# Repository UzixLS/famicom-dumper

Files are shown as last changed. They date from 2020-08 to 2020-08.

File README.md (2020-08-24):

# Famicom Dumper/Programmer

## Overview

This is simple dumper/programmer for Famicom cartridges.

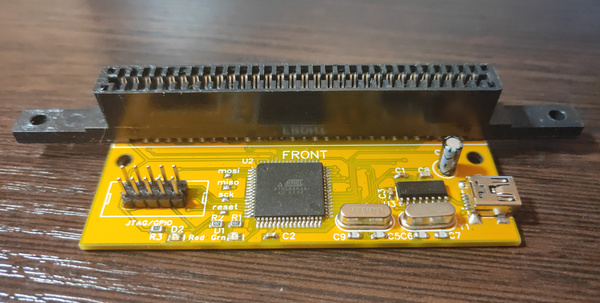
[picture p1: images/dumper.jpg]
Dumper


You can use it to:
* Dump cartridges, so you can play copy of your cartridge on emulator
* Read/write battery backed saves, so you can continue your saved game on emulator/console
* Write special cartridges like [COOLGIRL](https://github.com/ClusterM/coolgirl-famicom-multicard)
* Rewrite ultracheap chinese COOLBOY cartridges. Soldering required but it's very simple.
* Test your cartridges
* Some reverse engineering
* Anything else that requires Famicom bus simulation

## Schematics and parts list

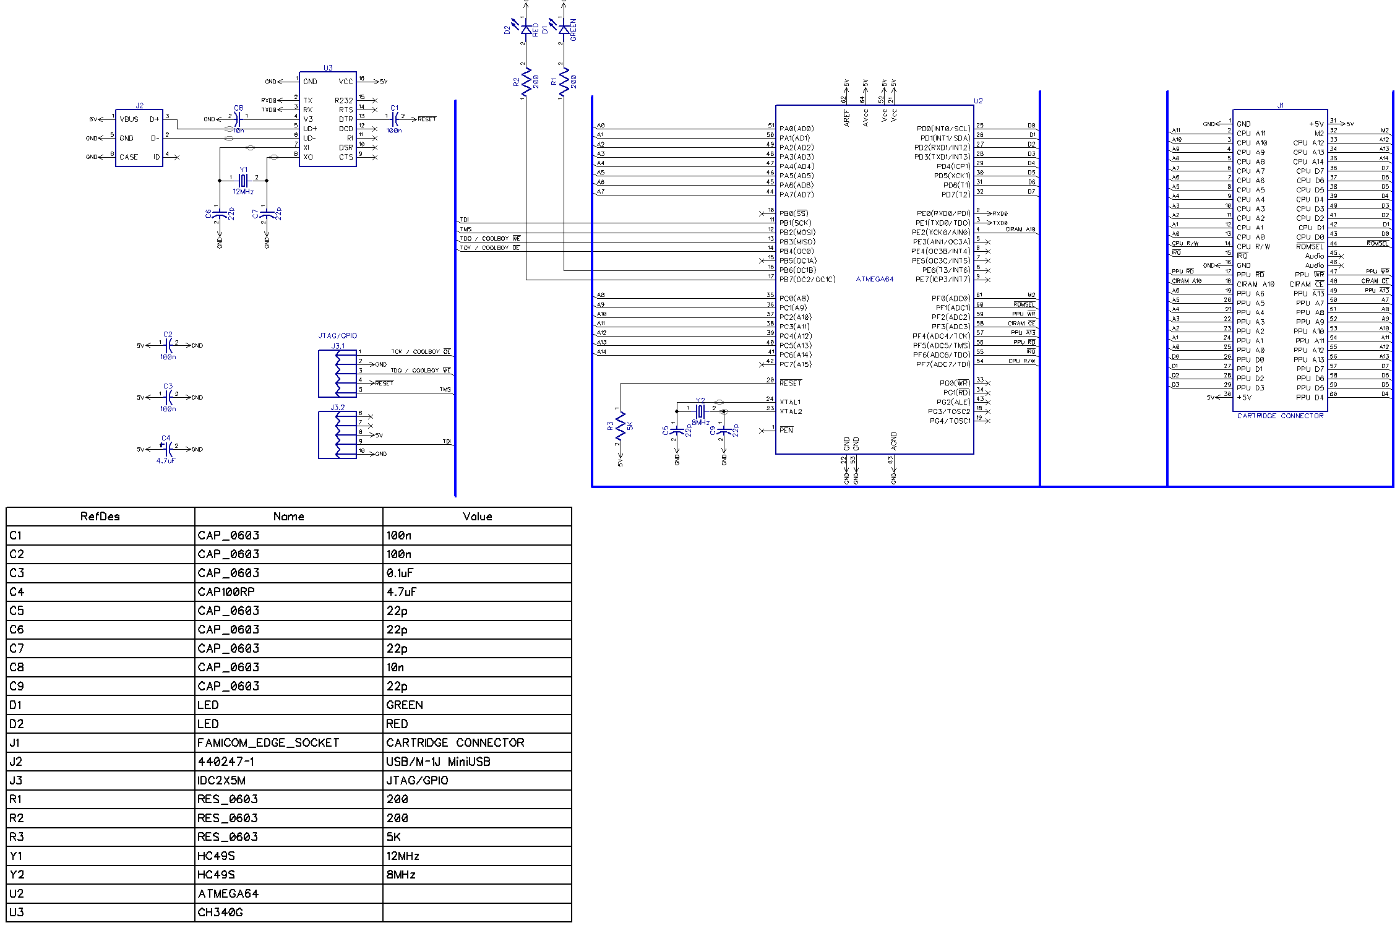
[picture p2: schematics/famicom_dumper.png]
Schematics


You need:
* ATMEGA64
* CH340G
* 60-pin edge socket
* Printed circuit board, you can order one using files it "board" or "board2" folders.
* Some capacitors
* Maybe some leds

That's all!

## How to compile firmware

All you need is [WinAVR](http://winavr.sourceforge.net/). Just type "make hex" in command line to compile firmware or bootloader.

## How to build it

You need to flash ATMEGA64 microcontroll using any AVR programmer. It's recommended to program bootloader first, so you can flash/update firmware via USB. I'm using bootloader by Martin Thomas, you can use already configured one in bootloader folder. There are fuses for it:
* LFUSE          = E4
* HFUSE          = DC
* EFUSE          = FF

You can program it using command like "**make program PROGRAMMER_TYPE=avrisp2 PROGRAMMER_PORT=usb**" from *bootloader* folder. Don't forget to replace *avrisp2* and *usb* with you programmer type and port.

Connect device to USB and PC will detect it as virtual serial port. First 8 seconds after power up bootloader is active (all leds are on), so you can program main firmware.

You can use command "**make program PROGRAMMER_PORT=COM10**" to program main firmware. Replace *COM10* with port assigned to your dumper (you can use Windows device manager to see it).

That's all! You can use it now.

## How to use it

Now you need PC-side client to use it: https://github.com/ClusterM/famicom-dumper-client

## How to rewrite COOLBOY cartridges

There are ultracheap chinese COOLBOY cartridges like "400 in 1" or "198 in 1". You can buy them on eBay or Aliexpress. And yes, there is flash memory, so you can rewrite it.

But you need to unsolder pins /OE and /WE and connect them to TCK and TDO pins on JTAG connector:

COOLBOY

Don't forget to solder pins back before using cartridge.

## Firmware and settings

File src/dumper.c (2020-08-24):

/* Famicom Dumper/Programmer
 *
 * Copyright notice for this file:
 *  Copyright (C) 2016 Cluster
 *  http://clusterrr.com
 *  clusterrr@clusterrr.com
 *
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
 */

#include "defines.h"
#include <avr/io.h>
#include <avr/interrupt.h>
#include <avr/wdt.h>
#include <util/delay.h>
#include <inttypes.h>
#include "usart.h"
#include "comm.h"
#include "jtag.h"

#define LED_RED_ON PORTB |= (1<<7)
#define LED_RED_OFF PORTB &= ~(1<<7)
#define LED_GREEN_ON PORTB |= (1<<6)
#define LED_GREEN_OFF PORTB &= ~(1<<6)
#define ROMSEL_HI PORTF |= (1<<1)
#define ROMSEL_LOW PORTF &= ~(1<<1)
#define PHI2_HI PORTF |= (1<<0)
#define PHI2_LOW PORTF &= ~(1<<0)
#define MODE_READ { PORTD = 0xFF; DDRD = 0; }
#define MODE_WRITE DDRD = 0xFF
#define PRG_READ PORTF |= (1<<7)
#define PRG_WRITE PORTF &= ~(1<<7)
#define CHR_READ_HI PORTF |= (1<<5)
#define CHR_READ_LOW PORTF &= ~(1<<5)
#define CHR_WRITE_HI PORTF |= (1<<2)
#define CHR_WRITE_LOW PORTF &= ~(1<<2)

static void (*jump_to_bootloader)(void) = (void*)0xF800;

ISR(USART0_RX_vect)
{
	unsigned char b;
	while (UCSR0A & (1<<RXC0))
	{
		b = UDR0;
		comm_proceed(b);
	}
}

static void phi2_init()
{
	int i = 0x80;
	unsigned char h = PORTF |= (1<<0);
	unsigned char l = PORTF &= ~(1<<0);
	while(i != 0){
		PORTA = l;
		PORTA = h;
		i--;
	}
}

static void set_address(unsigned int address)
{
	unsigned char l = address & 0xFF;
	unsigned char h = address>>8;
	
	PORTA = l;
	PORTC = h;
	
	// PPU /A13
	if ((address >> 13) & 1)
		PORTF &= ~(1<<4);
	else
		PORTF |= 1<<4;
}

static void set_romsel(unsigned int address)
{
	if (address & 0x8000)
	{
		ROMSEL_LOW;
	} else {
		ROMSEL_HI;
	}
}

static unsigned char read_prg_byte(unsigned int address)
{
	MODE_READ;
	PRG_READ;	
	set_address(address);
	PHI2_HI;
	set_romsel(address);
	_delay_us(1);
	return PIND;
}

static unsigned char read_chr_byte(unsigned int address)
{
	MODE_READ;
	PHI2_HI;
	ROMSEL_HI;
	set_address(address);
	CHR_READ_LOW;
	
	_delay_us(1);
	
	uint8_t result = PIND;
	
	CHR_READ_HI;
	return result;
}

static unsigned char read_coolboy_byte(unsigned int address)
{
	MODE_READ;
	PRG_READ;	
	set_address(address);
	PHI2_HI;
	ROMSEL_LOW;
	PORTB |= 1<<TDO_PIN;
	PORTB &= ~(1<<TCK_PIN);
	_delay_us(1);
	return PIND;
}

static void read_prg_send(unsigned int address, unsigned int len)
{
	LED_GREEN_ON;
	comm_start(COMMAND_PRG_READ_RESULT, len);
	while (len > 0)
	{
		comm_send_byte(read_prg_byte(address));
		len--;
		address++;
	}
	set_address(0);
	PHI2_HI;
	ROMSEL_HI;
	LED_GREEN_OFF;
}

static void read_chr_send(unsigned int address, unsigned int len)
{
	LED_GREEN_ON;
	comm_start(COMMAND_CHR_READ_RESULT, len);
	while (len > 0)
	{
		comm_send_byte(read_chr_byte(address));
		len--;
		address++;
	}
	set_address(0);
	PHI2_HI;
	ROMSEL_HI;
	LED_GREEN_OFF;
}

static uint16_t crc16_update(uint16_t crc, uint8_t a)
{
	int i;
	crc ^= a;
	for (i = 0; i < 8; ++i)
	{
		if (crc & 1)
			crc = (crc >> 1) ^ 0xA001;
		else
			crc = (crc >> 1);
	}
	return crc;
}

static void read_prg_crc_send(unsigned int address, unsigned int len)
{
	LED_GREEN_ON;
	uint16_t crc = 0;
	read_prg_byte(address);
	while (len > 0)
	{
		unsigned char l = address & 0xFF;
		unsigned char h = address>>8;	
		PORTA = l;
		PORTC = h;
		_delay_us(1);
		crc = crc16_update(crc, PIND);
		len--;
		address++;
	}
	set_address(0);
	PHI2_HI;
	ROMSEL_HI;
	comm_start(COMMAND_PRG_READ_RESULT, 2);
	comm_send_byte(crc & 0xFF);
	comm_send_byte((crc >> 8) & 0xFF);
	LED_GREEN_OFF;
}

static void read_chr_crc_send(unsigned int address, unsigned int len)
{
	LED_GREEN_ON;
	uint16_t crc = 0;
	while (len > 0)
	{
		crc = crc16_update(crc, read_chr_byte(address));
		len--;
		address++;
	}
	set_address(0);
	PHI2_HI;
	ROMSEL_HI;
	comm_start(COMMAND_CHR_READ_RESULT, 2);
	comm_send_byte(crc & 0xFF);
	comm_send_byte((crc >> 8) & 0xFF);
	LED_GREEN_OFF;
}

static void read_coolboy_send(unsigned int address, unsigned int len)
{
	LED_GREEN_ON;
	PORTB |= 1<<TCK_PIN;
	PORTB |= 1<<TDO_PIN;
	DDRB |= 1<<TCK_PIN;
	DDRB |= 1<<TDO_PIN;
	comm_start(COMMAND_PRG_READ_RESULT, len);
	while (len > 0)
	{
		comm_send_byte(read_coolboy_byte(address));
		len--;
		address++;
	}
	set_address(0);
	ROMSEL_HI;
	PORTB |= 1<<TCK_PIN;
	PORTB |= 1<<TDO_PIN;
	
	jtag_shutdown();
	LED_GREEN_OFF;
}

static void write_prg_byte(unsigned int address, uint8_t data)
{
	PHI2_LOW;
	ROMSEL_HI;
	MODE_WRITE;
	PRG_WRITE;
	PORTD = data;
	set_address(address); // PHI2 low, ROMSEL always HIGH
//	_delay_us(1);
	
	PHI2_HI;
	//_delay_us(10);
	set_romsel(address); // ROMSEL is low if need, PHI2 high	
	
	_delay_us(1); // WRITING
	//_delay_ms(1); // WRITING
	
	// PHI2 low, ROMSEL high
	PHI2_LOW;
	_delay_us(1);
	ROMSEL_HI;
	
	// Back to read mode
//	_delay_us(1);
	PRG_READ;
	MODE_READ;
	set_address(0);

	// Set phi2 to high state to keep cartridge unreseted
//	_delay_us(1);
	PHI2_HI;

//	_delay_us(1);
}

static void write_chr_byte(unsigned int address, uint8_t data)
{
	PHI2_LOW;
	ROMSEL_HI;
	MODE_WRITE;
	PORTD = data;	
	set_address(address); // PHI2 low, ROMSEL always HIGH
	//_delay_us(10);
	
	CHR_WRITE_LOW;
		
	_delay_us(1); // WRITING
	//_delay_ms(1); // WRITING
	
	CHR_WRITE_HI;
	
	//_delay_us(1);
	
	MODE_READ;
	set_address(0);
	PHI2_HI;
	
	//_delay_us(1);
}

static void write_prg(unsigned int address, unsigned int len, uint8_t* data)
{
	LED_RED_ON;
	while (len > 0)
	{
		write_prg_byte(address, *data);
		address++;
		len--;
		data++;
	}
	//_delay_ms(1);
	LED_RED_OFF;
}

static void write_chr(unsigned int address, unsigned int len, uint8_t* data)
{
	LED_RED_ON;
	while (len > 0)
	{
		write_chr_byte(address, *data);
		address++;
		len--;
		data++;
	}
	//_delay_ms(1);
	LED_RED_OFF;
}

static void write_prg_flash_command(unsigned int address, uint8_t data)
{
	write_prg_byte(address | 0x8000, data);
}

static void write_coolboy_flash_command(unsigned int address, uint8_t data)
{
	PORTB |= 1<<TCK_PIN;
	PORTB |= 1<<TDO_PIN;
	ROMSEL_HI;
	PRG_READ;	
	set_address(address);
	MODE_WRITE;
	PORTD = data;
	PHI2_HI;
	ROMSEL_LOW;
	_delay_us(1);
	
	PORTB &= ~(1<<TDO_PIN);
	
	_delay_us(1);

	PORTB |= 1<<TDO_PIN;
	set_address(0);
	ROMSEL_HI;
	MODE_READ;
}

static void write_chr_flash_command(unsigned int address, uint8_t data)
{
	write_chr_byte(address, data);
}

static int write_prg_flash_byte(unsigned int address, uint8_t data)
{
	write_prg_flash_command(0x0000, 0xF0);
	write_prg_flash_command(0x0555, 0xAA);
	write_prg_flash_command(0x02AA, 0x55);
	write_prg_flash_command(0x0555, 0xA0);
	
	write_prg_flash_command(address, data);
	_delay_us(50);

	int timeout = 0;
	uint8_t res, last_res = 0;
	while (timeout < 200)
	{
		res = read_prg_byte(address | 0x8000);
		ROMSEL_HI;
		if (res == last_res && last_res == data) break;
		last_res = res;
 		_delay_us(50);
		timeout++;
	}
	//PHI2_LOW;
	ROMSEL_HI;
	set_address(0);
	
	return timeout < 10;
}


static int write_chr_flash_byte(unsigned int address, uint8_t data)
{
	write_chr_flash_command(0x0000, 0xF0);
	write_chr_flash_command(0x0555, 0xAA);
	write_chr_flash_command(0x02AA, 0x55);
	write_chr_flash_command(0x0555, 0xA0);
	write_chr_flash_command(address, data);

	int timeout = 0;
	while (read_chr_byte(address | 0x8000) != data && timeout < 10)
	{
		_delay_us(100);
		timeout++;
	}
	set_address(0);
	PHI2_LOW;
	ROMSEL_HI;
	
	return timeout < 10;
}

static int erase_prg_flash()
{
	LED_RED_ON;
	write_prg_flash_command(0x0000, 0xF0);
	write_prg_flash_command(0x0AAA, 0xAA);
	write_prg_flash_command(0x0555, 0x55);
	write_prg_flash_command(0x0AAA, 0x80);
	write_prg_flash_command(0x0AAA, 0xAA);
	write_prg_flash_command(0x0555, 0x55);
	write_prg_flash_command(0x0AAA, 0x10);
	
	int timeout = 0;
	while ((read_prg_byte(0x8000) != 0xFF) && (timeout < 300000))
	{
		_delay_ms(1);
		timeout++;
	}
	set_address(0);
	PHI2_HI;
	ROMSEL_HI;

	LED_RED_OFF;
	return timeout < 300000;
}

static int erase_coolboy_sector()
{
	LED_RED_ON;
	PORTB |= 1<<TCK_PIN;
	PORTB |= 1<<TDO_PIN;
	DDRB |= 1<<TCK_PIN;
	DDRB |= 1<<TDO_PIN;
	ROMSEL_HI;

	write_coolboy_flash_command(0x0000, 0xF0);
	write_coolboy_flash_command(0x0AAA, 0xAA);
	write_coolboy_flash_command(0x0555, 0x55);
	write_coolboy_flash_command(0x0AAA, 0x80);
	write_coolboy_flash_command(0x0AAA, 0xAA);
	write_coolboy_flash_command(0x0555, 0x55);
	write_coolboy_flash_command(0x0000, 0x30);	
	
	int timeout = 0;
	uint8_t debug;
	while (((debug = read_coolboy_byte(0x8000)) != 0xFF) && (timeout < 3000))
	{
		//comm_start(0xFF, 1);
		//comm_send_byte(debug);
		_delay_ms(1);
		timeout++;
	}
	
	set_address(0);
	ROMSEL_HI;

	jtag_shutdown();
	LED_RED_OFF;
	return timeout < 3000;
}

static int erase_coolgirl_sector()
{
	LED_RED_ON;
	write_prg_flash_command(0x0000, 0xF0);
	write_prg_flash_command(0x0AAA, 0xAA);
	write_prg_flash_command(0x0555, 0x55);
	write_prg_flash_command(0x0AAA, 0x80);
	write_prg_flash_command(0x0AAA, 0xAA);
	write_prg_flash_command(0x0555, 0x55);
	write_prg_flash_command(0x0000, 0x30);
	
	int timeout = 0;
	uint8_t debug;
	while (((debug = read_prg_byte(0x8000)) != 0xFF) && (timeout < 3000))
	{
		ROMSEL_HI;
		//comm_start(0xFF, 1);
		//comm_send_byte(debug);
		_delay_ms(1);
		timeout++;
	}	
	//comm_start(0xFF, 1);
	//comm_send_byte(debug);
	set_address(0);
	PHI2_HI;
	ROMSEL_HI;

	LED_RED_OFF;
	return timeout < 3000;
}

static int erase_chr_flash()
{
	LED_RED_ON;
	write_chr_flash_command(0x0000, 0xF0);
	write_chr_flash_command(0x0555, 0xAA);
	write_chr_flash_command(0x02AA, 0x55);
	write_chr_flash_command(0x0555, 0x80);
	write_chr_flash_command(0x0555, 0xAA);
	write_chr_flash_command(0x02AA, 0x55);
	write_chr_flash_command(0x0555, 0x10);
	
	int timeout = 0;
	while ((read_chr_byte(0) != 0xFF) && (timeout < 10000))
	{
		_delay_ms(1);
		timeout++;
	}
	set_address(0);
	PHI2_HI;
	ROMSEL_HI;

	LED_RED_OFF;
	return timeout < 10000;
}

static int write_prg_flash(unsigned int address, unsigned int len, uint8_t* data)
{
	LED_RED_ON;
	int ok = 1;
	while (len > 0)
	{
		if (!write_prg_flash_byte(address, *data))
		{
			ok = 0;
			break;
		}
		address++;
		len--;
		data++;
	}
	LED_RED_OFF;
	return ok;
}

static int write_coolboy(unsigned int address, unsigned int len, uint8_t* data)
{
	LED_RED_ON;
	PORTB |= 1<<TCK_PIN;
	PORTB |= 1<<TDO_PIN;
	DDRB |= 1<<TCK_PIN;
	DDRB |= 1<<TDO_PIN;
	ROMSEL_HI;
	uint8_t ok = 1;
	while (len > 0)
	{
		
		//uint8_t count = len > 16 ? 16 : len;
		uint8_t count = 0;
		uint8_t* d = data;
		unsigned int a = address;
		unsigned int address_base = a & 0xFFE0;
		while (len > 0 && ((a & 0xFFE0) == address_base))
		{
			if (*d != 0xFF) count++;
			a++;
			len--;
			d++;
		}

		if (count)
		{
			//write_prg_flash_command(0x0000, 0xF0);
			write_coolboy_flash_command(0x0AAA, 0xAA);
			write_coolboy_flash_command(0x0555, 0x55);
			write_coolboy_flash_command(0x0000, 0x25);
			write_coolboy_flash_command(0x0000, count-1);

			while (count > 0)
			{
				if (*data != 0xFF)
				{
					write_coolboy_flash_command(address, *data);
					count--;
				}
				address++;
				data++;
			}
		
			write_coolboy_flash_command(0x0000, 0x29);
			_delay_us(10);

			long int timeout = 0;
			uint8_t res, last_res = 0;
			while (timeout < 100000)
			{
				res = read_coolboy_byte((address-1) | 0x8000);
				ROMSEL_HI;
				if (res == last_res && last_res == *(data-1)) break;
				last_res = res;
				_delay_us(10);
				timeout++;
			}
			if (timeout >= 100000)
			{
				ok = 0;
				break;
			}
		}
		
		address = a;
		data = d;
	}
	ROMSEL_HI;
	jtag_shutdown();
	LED_RED_OFF;
	return ok;
}

static int write_coolgirl(unsigned int address, unsigned int len, uint8_t* data)
{
	LED_RED_ON;
	ROMSEL_HI;
	uint8_t ok = 1;
	while (len > 0)
	{
		
		//uint8_t count = len > 16 ? 16 : len;
		uint8_t count = 0;
		uint8_t* d = data;
		unsigned int a = address;
		unsigned int address_base = a & 0xFFE0;
		while (len > 0 && ((a & 0xFFE0) == address_base))
		{
			if (*d != 0xFF)
				count++;
			a++;
			len--;
			d++;
		}

		if (count)
		{
			write_prg_flash_command(0x0000, 0xF0);
			write_prg_flash_command(0x0AAA, 0xAA);
			write_prg_flash_command(0x0555, 0x55);
			write_prg_flash_command(0x0000, 0x25);
			write_prg_flash_command(0x0000, count-1);

			while (count > 0)
			{
				if (*data != 0xFF)
				{
					write_prg_flash_command(address, *data);
					count--;
				}
				address++;
				data++;
			}
		
			write_prg_flash_command(0x0000, 0x29);
			_delay_us(10);

			long int timeout = 0;
			uint8_t res, last_res = 0;
			while (timeout < 100000)
			{
				res = read_prg_byte((address-1) | 0x8000);
				//comm_start(0xFF, 1);
				//comm_send_byte(res);
				ROMSEL_HI;
				if (res == last_res && last_res == *(data-1)) break;
				last_res = res;
				_delay_us(10);
				timeout++;
			}
			//comm_start(0xFF, 1);
			//comm_send_byte(res);
			if (timeout >= 100000)
			{
				ok = 0;
				break;
			}
		}

		address = a;
		data = d;
	}
	ROMSEL_HI;
	LED_RED_OFF;
	return ok;
}

static int write_chr_flash(unsigned int address, unsigned int len, uint8_t* data)
{
	LED_RED_ON;
	if (address >= 0x8000) address -= 0x8000;
	int ok = 1;
	while (len > 0)
	{
		if (!write_chr_flash_byte(address, *data))
		{
			ok = 0;
			break;
		}
		address++;
		len--;
		data++;
	}
	LED_RED_OFF;
	return ok;
}

void get_mirroring()
{
	comm_start(COMMAND_MIRRORING_RESULT, 4);
	LED_GREEN_ON;
	set_address(0);
	_delay_us(1);
	comm_send_byte((PINE >> 2) & 1);
	set_address(1<<10);
	_delay_us(1);
	comm_send_byte((PINE >> 2) & 1);
	set_address(1<<11);
	_delay_us(1);
	comm_send_byte((PINE >> 2) & 1);
	set_address((1<<10) | (1<<11));
	_delay_us(1);
	comm_send_byte((PINE >> 2) & 1);
	set_address(0);
}

static void init_ports()
{
	DDRB |= (1 << 6) | (1 << 7); // LEDS
	DDRF = 0b10110111; // CPU R/W, IRQ, PPU /RD, PPU /A13, CIRAM /CE, PPU /WR, /ROMSEL, PHI2
	PORTF = 0b11111111; // CPU R/W, IRQ, PPU /RD, PPU /A13, CIRAM /CE, PPU /WR, /ROMSEL, PHI2	
	DDRE &= ~(1<<2); // CIRAM A10
	PORTE |= 1<<2; // CIRAM A10
	MODE_READ;
	set_address(0);
	DDRA = 0xFF; // Address low	
	DDRC = 0xFF; // Address high
}

static void reset_phi2()
{
	LED_RED_ON;
	LED_GREEN_ON;
	PHI2_LOW;
	ROMSEL_HI;
	_delay_ms(100);
	PHI2_HI;
	LED_RED_OFF;
	LED_GREEN_OFF;
}

int main (void)
{
	sei();
	USART_init();
	init_ports();
	jtag_shutdown();

	LED_RED_OFF;
	LED_GREEN_OFF;	
	
	comm_init();
	comm_start(COMMAND_PRG_STARTED, 0);

	uint16_t address;
	uint16_t length;
	
	unsigned long int t = 0;
	char led_down = 0;
	int led_bright = 0;
	
	while (1)
	{
		TCCR1A |= (1<<COM1C1) | (1<<COM1B1) | (1<<WGM10);
		TCCR1B |= (1<<CS10);
		if (t++ >= 10000)
		{
			if (!led_down)
			{
				led_bright++;
				if (led_bright >= 110) led_down = 1;
			} else {
				led_bright--;
				if (!led_bright) led_down = 0;
			}
			if (led_bright >= 100) OCR1B = led_bright - 100;
			if (led_down)
			{
				int led_bright2 = 110-led_bright;
				if (led_bright2 <= 20)
				{
					if (led_bright2 > 10) led_bright2 = 20 - led_bright2;
					OCR1C = led_bright2*2;
				}
			}
			t = 0;
		}
		
		if (comm_recv_done)
		{
			comm_recv_done = 0;
			t = led_down = led_bright = 0;
			TCCR1A = OCR1B = OCR1C = 0;
			
			switch (comm_recv_command)
			{
				case COMMAND_PRG_INIT:
					comm_start(COMMAND_PRG_STARTED, 0);
					break;
					
				case COMMAND_PRG_READ_REQUEST:
					address = recv_buffer[0] | ((uint16_t)recv_buffer[1]<<8);
					length = recv_buffer[2] | ((uint16_t)recv_buffer[3]<<8);
					read_prg_send(address, length);
					break;

				case COMMAND_PRG_CRC_READ_REQUEST:
					address = recv_buffer[0] | ((uint16_t)recv_buffer[1]<<8);
					length = recv_buffer[2] | ((uint16_t)recv_buffer[3]<<8);
					read_prg_crc_send(address, length);
					break;

				case COMMAND_PRG_WRITE_REQUEST:
					address = recv_buffer[0] | ((uint16_t)recv_buffer[1]<<8);
					length = recv_buffer[2] | ((uint16_t)recv_buffer[3]<<8);
					write_prg(address, length, (uint8_t*)&recv_buffer[4]);
					comm_start(COMMAND_PRG_WRITE_DONE, 0);
					break;

				case COMMAND_COOLBOY_READ_REQUEST:
					address = recv_buffer[0] | ((uint16_t)recv_buffer[1]<<8);
					length = recv_buffer[2] | ((uint16_t)recv_buffer[3]<<8);
					read_coolboy_send(address, length);
					break;

				case COMMAND_PHI2_INIT:
					phi2_init();
					comm_start(COMMAND_PHI2_INIT_DONE, 0);
					break;

				case COMMAND_RESET:
					reset_phi2();
					comm_start(COMMAND_RESET_ACK, 0);
					break;
					
				case COMMAND_PRG_FLASH_ERASE_REQUEST:
					if (erase_prg_flash())
						comm_start(COMMAND_PRG_WRITE_DONE, 0);
					break;

				case COMMAND_PRG_FLASH_WRITE_REQUEST:
					address = recv_buffer[0] | ((uint16_t)recv_buffer[1]<<8);
					length = recv_buffer[2] | ((uint16_t)recv_buffer[3]<<8);
					if (write_prg_flash(address, length, (uint8_t*)&recv_buffer[4]))
						comm_start(COMMAND_PRG_WRITE_DONE, 0);
					break;
					
				case COMMAND_COOLBOY_ERASE_REQUEST:
					if (erase_coolboy_sector())
						comm_start(COMMAND_PRG_WRITE_DONE, 0);
					break;

				case COMMAND_COOLBOY_WRITE_REQUEST:
					address = recv_buffer[0] | ((uint16_t)recv_buffer[1]<<8);
					length = recv_buffer[2] | ((uint16_t)recv_buffer[3]<<8);
					if (write_coolboy(address, length, (uint8_t*)&recv_buffer[4]))
						comm_start(COMMAND_PRG_WRITE_DONE, 0);
					break;
					
				case COMMAND_COOLGIRL_ERASE_SECTOR_REQUEST:
					if (erase_coolgirl_sector())
						comm_start(COMMAND_PRG_WRITE_DONE, 0);
					break;

				case COMMAND_COOLGIRL_WRITE_REQUEST:
					address = recv_buffer[0] | ((uint16_t)recv_buffer[1]<<8);
					length = recv_buffer[2] | ((uint16_t)recv_buffer[3]<<8);
					if (write_coolgirl(address, length, (uint8_t*)&recv_buffer[4]))
						comm_start(COMMAND_PRG_WRITE_DONE, 0);
					break;
					
				case COMMAND_CHR_INIT:
					comm_start(COMMAND_CHR_STARTED, 0);
					break;
					
				case COMMAND_CHR_READ_REQUEST:
					address = recv_buffer[0] | ((uint16_t)recv_buffer[1]<<8);
					length = recv_buffer[2] | ((uint16_t)recv_buffer[3]<<8);
					read_chr_send(address, length);
					break;

				case COMMAND_CHR_CRC_READ_REQUEST:
					address = recv_buffer[0] | ((uint16_t)recv_buffer[1]<<8);
					length = recv_buffer[2] | ((uint16_t)recv_buffer[3]<<8);
					read_chr_crc_send(address, length);
					break;

				case COMMAND_CHR_WRITE_REQUEST:
					address = recv_buffer[0] | ((uint16_t)recv_buffer[1]<<8);
					length = recv_buffer[2] | ((uint16_t)recv_buffer[3]<<8);
					write_chr(address, length, (uint8_t*)&recv_buffer[4]);
					comm_start(COMMAND_CHR_WRITE_DONE, 0);
					break;

				case COMMAND_MIRRORING_REQUEST:
					get_mirroring();
					break;

				/*
				case COMMAND_EPROM_PREPARE:
					write_eprom_prepare();
					break;
				
				case COMMAND_CHR_EPROM_WRITE_REQUEST:
					address = recv_buffer[0] | ((uint16_t)recv_buffer[1]<<8);
					length = recv_buffer[2] | ((uint16_t)recv_buffer[3]<<8);
					write_eprom(address, length, (uint8_t*)&recv_buffer[4]);
					comm_start(COMMAND_CHR_WRITE_DONE, 0);
					break;
				*/
					
				case COMMAND_CHR_FLASH_ERASE_REQUEST:
					if (erase_chr_flash())
						comm_start(COMMAND_CHR_WRITE_DONE, 0);
					break;

				case COMMAND_CHR_FLASH_WRITE_REQUEST:
					address = recv_buffer[0] | ((uint16_t)recv_buffer[1]<<8);
					length = recv_buffer[2] | ((uint16_t)recv_buffer[3]<<8);
					if (write_chr_flash(address, length, (uint8_t*)&recv_buffer[4]))
						comm_start(COMMAND_CHR_WRITE_DONE, 0);
					break;
					
				case COMMAND_JTAG_SETUP:
					jtag_setup();
					comm_start(COMMAND_JTAG_RESULT, 1);
					comm_send_byte(1);
					break;
					
				case COMMAND_JTAG_SHUTDOWN:
					jtag_shutdown();
					comm_start(COMMAND_JTAG_RESULT, 1);
					comm_send_byte(1);
					break;
				
				case COMMAND_JTAG_EXECUTE:
					address = recv_buffer[0] | ((uint16_t)recv_buffer[1]<<8);
					comm_start(COMMAND_JTAG_RESULT, 1);
					LED_RED_ON;
					comm_send_byte(jtag_execute(address, (uint8_t*) &recv_buffer[2]));
					LED_RED_OFF;
					break;
				case COMMAND_BOOTLOADER:
					cli();
					MCUCSR = 0;
					jump_to_bootloader();
			}
		}		
	}
}

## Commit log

2020-08-24 remove old board files
    [famicom_dumper.drl, famicom_dumper_board_outline.gbr, famicom_dumper_copper_bottom.gbr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]
2020-08-24 update schematic and board: use cheap ch340 instead of ft232rl
    [BoardOutline.gbr, Bottom.gbr, BottomMask.gbr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]
2020-08-24 update bom
2020-08-24 update schematic png file
